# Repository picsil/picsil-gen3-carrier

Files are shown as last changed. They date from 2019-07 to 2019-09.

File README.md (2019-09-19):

# picsil-gen3-carrier
A carrier board for Particle Boron with support for three OneWire or dry contact sensors, onboard 32KB FRAM and DS18B20 temperature sensor, and ESD protected sensor inputs.

## NOTE
There are known problems with this circuit. Be aware of this before using it, since you will need to make changes.

### Known issues:
- J1-J3 use the wrong footprint. It uses STX-3120-3BM (mono), where it should be STX-3120-3B (stereo).
- U4 uses the wrong footprint, at least for the parts I have. I was unable to find a part that uses the footprint in this design.
- D4 is potentially a problem. Consider removing it if unsure.

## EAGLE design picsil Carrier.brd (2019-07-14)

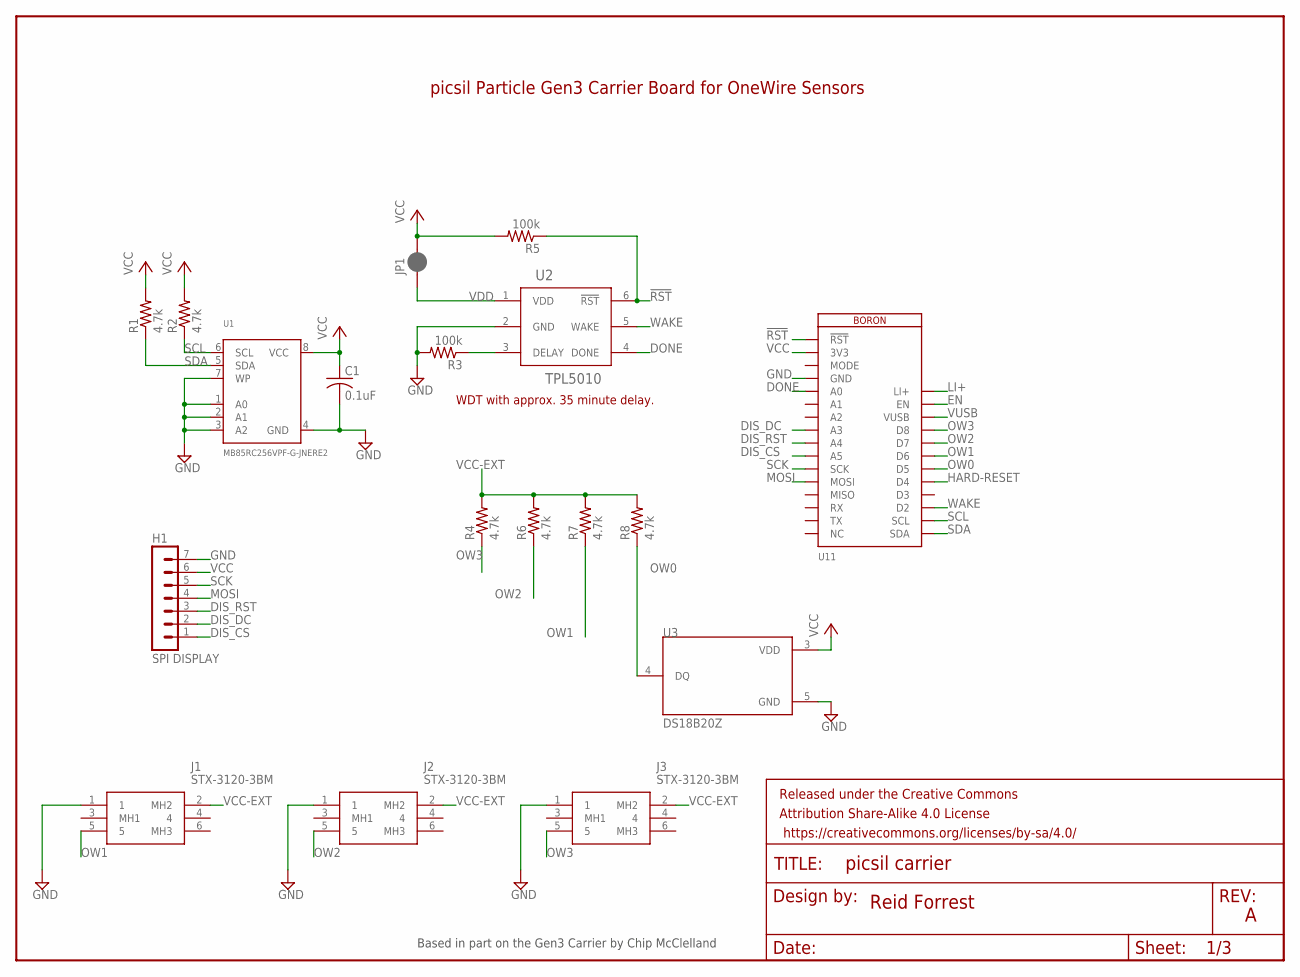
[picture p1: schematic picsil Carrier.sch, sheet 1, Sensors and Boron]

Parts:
C1: 0.1uF; C0805
FRAME1, FRAME4: FRAME-LETTER; CREATIVE_COMMONS
H1: SPI DISPLAY; MA07-1
J1, J2, J3: STX-3120-3BM; STX31203BM
JP1: JUMPER-SMT_2_NC_PASTE_SILK; SMT-JUMPER_2_NC_PASTE_SILK
R1, R2, R4, R6, R7, R8: 4.7k; R0805
R3, R5: 100k; R0805
U1: MB85RC256VPF-G-JNERE2; SOIC8_208MIL
U2: TPL5010; TSOT-23
U3: DS18B20Z; SOIC127P600X175-8N
U11: BORON

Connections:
!RST: R5.1, U2.6 (!RST), U11.1 (!RST)
DIS_CS: H1.1, U11.10 (A5)
DIS_DC: H1.2, U11.8 (A3)
DIS_RST: H1.3, U11.9 (A4)
DONE: U2.4 (DONE), U11.5 (A0)
EN: U11.27 (EN); also elsewhere on the board
GND: C1.2, H1.7, J1.1, J2.1, J3.1, R3.2, U1.1 (A0), U1.2 (A1), U1.3 (A2), U1.4 (GND), U1.7 (WP), U2.2 (GND), U3.5 (GND), U11.4 (GND); also elsewhere on the board
HARD-RESET: U11.21 (D4); also elsewhere on the board
LI+: U11.28 (LI+); also elsewhere on the board
MOSI: H1.4, U11.12 (MOSI)
unnamed: R3.1, U2.3 (DELAY)
OW0: R8.1, U3.4 (DQ), U11.22 (D5)
OW1: J1.5, R7.1, U11.23 (D6); also elsewhere on the board
OW2: J2.5, R6.1, U11.24 (D7); also elsewhere on the board
OW3: J3.5, R4.1, U11.25 (D8); also elsewhere on the board
SCK: H1.5, U11.11 (SCK)
SCL: R2.1, U1.6 (SCL), U11.18 (SCL)
SDA: R1.1, U1.5 (SDA), U11.17 (SDA)
VCC: C1.1, H1.6, JP1.2, R1.2, R2.2, R5.2, U1.8 (VCC), U3.3 (VDD), U11.2 (3V3); also elsewhere on the board
VCC-EXT: J1.2 (MH2), J2.2 (MH2), J3.2 (MH2), R4.2, R6.2, R7.2, R8.2; also elsewhere on the board
VDD: JP1.1, U2.1 (VDD)
VUSB: U11.26 (VUSB); also elsewhere on the board
WAKE: U2.5 (WAKE), U11.19 (D2)

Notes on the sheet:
WDT with approx. 35 minute delay.
picsil Particle Gen3 Carrier Board for OneWire Sensors
Reid Forrest
Based in part on the Gen3 Carrier by Chip McClelland

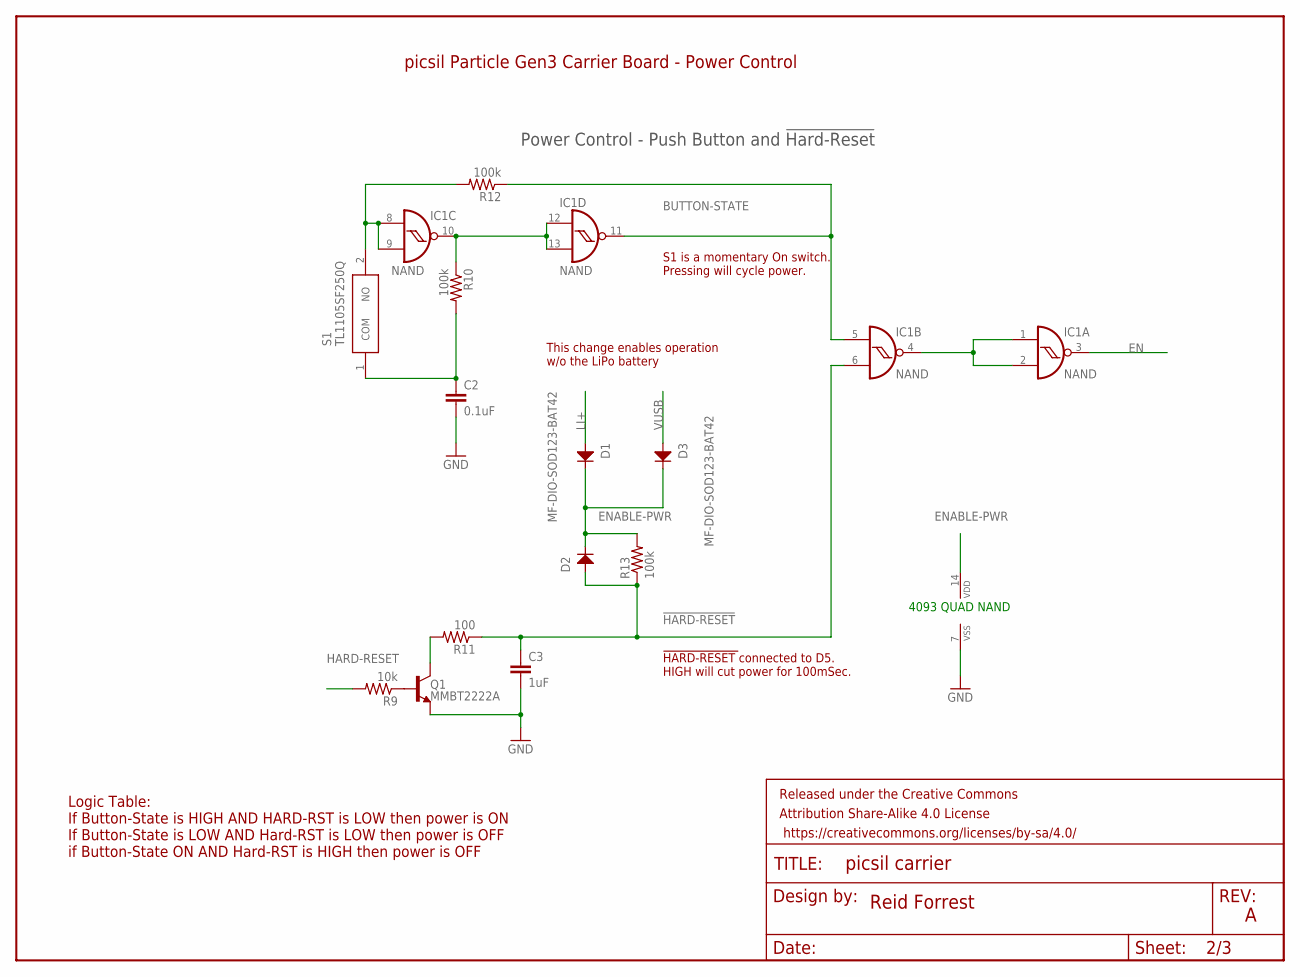
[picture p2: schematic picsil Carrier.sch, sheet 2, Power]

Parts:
C2: 0.1uF; 0805@1
C3: 1uF; 0805@1
D1, D2, D3: MF-DIO-SOD123-BAT42; SOD-123
FRAME2: FRAME-LETTER; CREATIVE_COMMONS
IC1: NAND; MC14093B-TSSOP14
Q1: MMBT2222A; SOT23-3
R9: 10k; 0805
R10, R12, R13: 100k; 0805
R11: 100; 0805
S1: TL1105SF250Q

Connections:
!HARD-RESET: C3.1, D2.ANODE, IC1.6 (I1), R11.1, R13.1
BUTTON-STATE: IC1.5 (I0), IC1.11 (O), R12.1
EN: IC1.3 (O); also elsewhere on the board
ENABLE-PWR: D1.CATHODE, D2.CATHODE, D3.CATHODE, IC1.14 (VDD), R13.2
GND: C2.2, C3.2, IC1.7 (VSS), Q1.2 (E); also elsewhere on the board
HARD-RESET: R9.2; also elsewhere on the board
LI+: D1.ANODE; also elsewhere on the board
unnamed: IC1.1 (I0), IC1.2 (I1), IC1.4 (O)
unnamed: IC1.10 (O), IC1.12 (I0), IC1.13 (I1), R10.1
unnamed: Q1.1 (B), R9.1
unnamed: Q1.3 (C), R11.2
unnamed: C2.1, R10.2, S1.1 (COM)
unnamed: IC1.8 (I0), IC1.9 (I1), R12.2, S1.2 (NO)
VUSB: D3.ANODE; also elsewhere on the board

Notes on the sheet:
4093 QUAD NAND
Power Control - Push Button and !Hard-Reset
Logic Table: If Button-State is HIGH AND HARD-RST is LOW then power is ON If Button-State is LOW AND Hard-RST is LOW then power is OFF if Button-State ON AND Hard-RST is HIGH then power is OFF
!HARD-RESET !connected to D5. HIGH will cut power for 100mSec.
S1 is a momentary On switch. Pressing will cycle power.
This change enables operation w/o the LiPo battery
picsil Particle Gen3 Carrier Board - Power Control
Reid Forrest

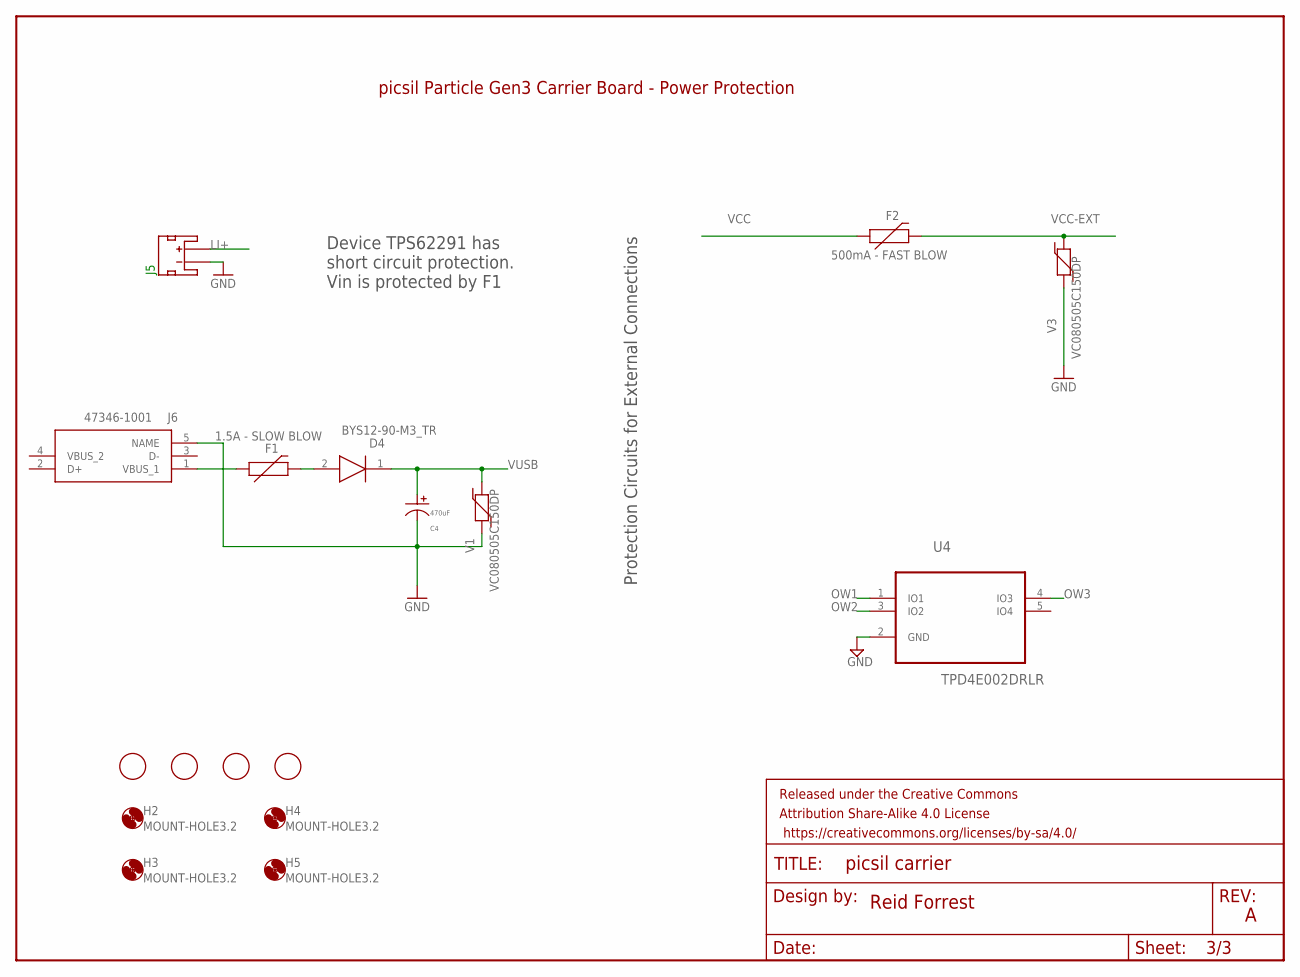
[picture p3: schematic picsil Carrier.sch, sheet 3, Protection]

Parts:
C4: 470uF; CP10MM
D4: BYS12-90-M3_TR; DIOM5127X229N
F1: 1.5A - SLOW BLOW; 1206
F2: 500mA - FAST BLOW; 1206
FRAME3: FRAME-LETTER; CREATIVE_COMMONS
H2, H3, H4, H5: MOUNT-HOLE3.2; 3,2
J5: S2B-PH-SM4-TB(LF)(SN); JST-2-SMD
J6: 47346-1001; 47346-0001
U4: TPD4E002DRLR; SOT50P280X60-5N
U$1, U$2, U$3, U$4: FIDUCIAL; FIDUCIAL_1MM
V1, V3: VC080505C150DP; 0805

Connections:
GND: C4.P$2, J5.1 (-), J6.5 (NAME), U4.2 (GND), V1.1, V3.1; also elsewhere on the board
LI+: J5.2 (+); also elsewhere on the board
unnamed: F1.1, J6.1 (VBUS_1)
unnamed: D4.2 (A), F1.2
OW1: U4.1 (IO1); also elsewhere on the board
OW2: U4.3 (IO2); also elsewhere on the board
OW3: U4.4 (IO3); also elsewhere on the board
VCC: F2.1; also elsewhere on the board
VCC-EXT: F2.2, V3.2; also elsewhere on the board
VUSB: C4.P$1, D4.1 (K), V1.2; also elsewhere on the board

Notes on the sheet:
Protection Circuits for External Connections
Device TPS62291 has short circuit protection. Vin is protected by F1
picsil Particle Gen3 Carrier Board - Power Protection
Reid Forrest

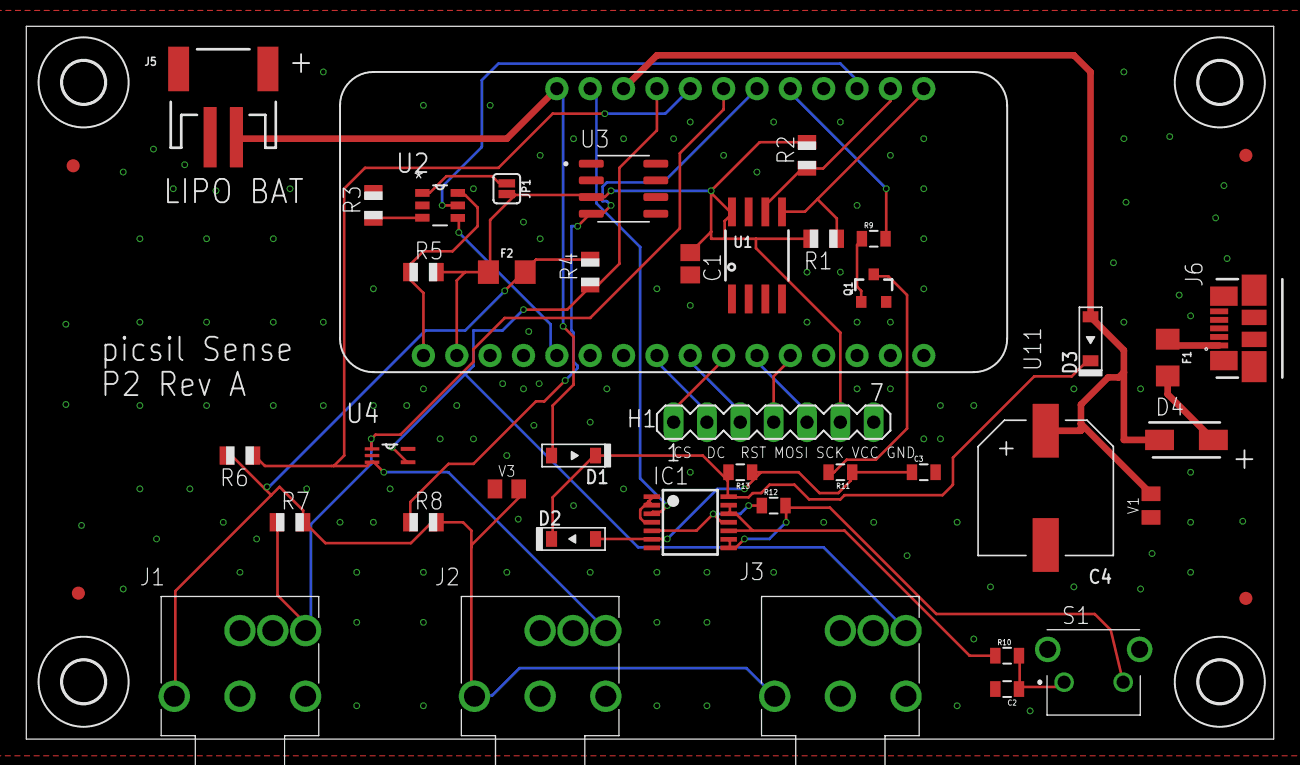
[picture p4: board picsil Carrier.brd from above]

Board: 2 copper layers, 95.0 x 54.3 mm, 52 parts (0 on the bottom side), 34 nets.

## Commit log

2019-07-06 updated brd
    [picsil Carrier.brd]
2019-07-07 mounting holes and fiducials
    [picsil Carrier.brd, picsil Carrier.sch]
2019-07-07 finalized Rev A
    [picsil Carrier.brd, picsil Carrier.sch]
2019-07-07 remove boron mounting holes
    [picsil Carrier.brd]
2019-07-07 added vias around GND
    [picsil Carrier.brd]
2019-07-08 rerouted VCC to U1
    [picsil Carrier.brd]
2019-07-14 Rev A
    [picsil Carrier.brd]

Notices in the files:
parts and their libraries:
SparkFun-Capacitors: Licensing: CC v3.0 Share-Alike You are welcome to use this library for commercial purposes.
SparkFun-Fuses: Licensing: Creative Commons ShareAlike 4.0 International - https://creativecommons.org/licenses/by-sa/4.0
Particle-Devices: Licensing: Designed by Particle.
